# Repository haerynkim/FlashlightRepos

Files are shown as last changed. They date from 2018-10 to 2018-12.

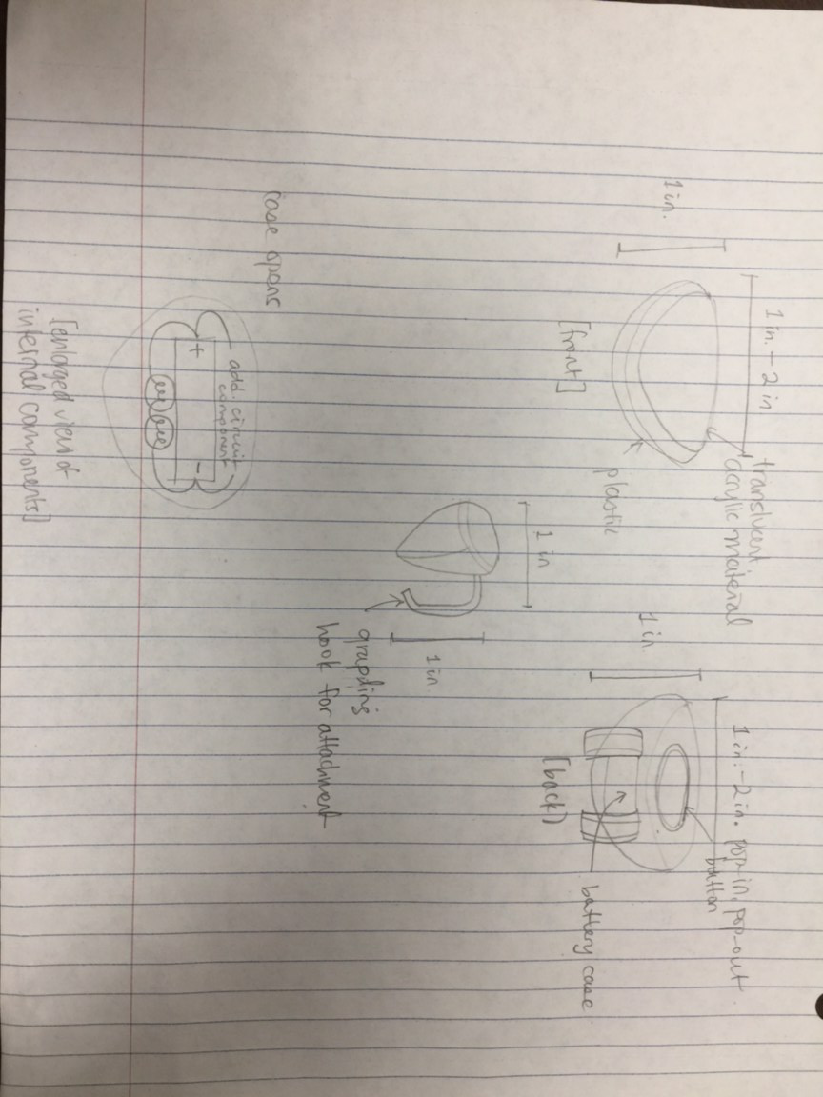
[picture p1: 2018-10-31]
design_sketch.jpeg

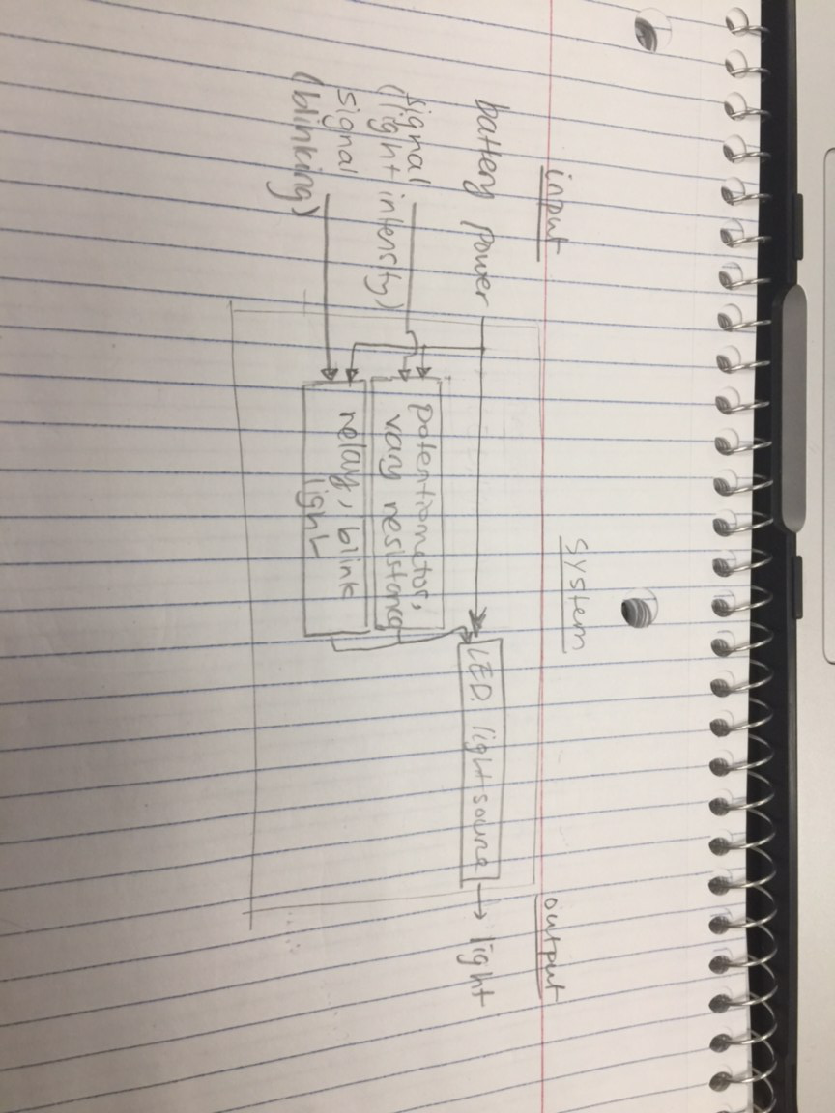
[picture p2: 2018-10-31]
block_diag.jpeg

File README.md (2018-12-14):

# FlashlightRepos
Final video submission URL: https://youtu.be/8UVXDF8A7WE<br/>
*note: I did not indicate on Sakai but I submitted course evaluations in class.

## How To
This design is protable lightbox and pulse sensor. To turn the device on, toggle the switch ON. An initiation screen will appear and in a few seconds, the red LED will turn on. To cycle through various modes, simply push down on the pushbutton. On every fourth push of the cycle, the LCD will display the pulse readings. You can attach or detach the pulse sensor at any moment by attaching or removing the earclip to your earlobes.<br/>
To replace the battery, simply open the box and unscrew the 1/8" bolts and expose the battery underneath. The battery cap is easily removable, and the battery replaceable.

## Features of the Device

### Software
* Debounce, interrupt on pushbutton
* Max BPM resets if max BPM remains over 215 bpm for greater than 20 seconds

### Hardware
* Green 3mm LED on PCB to indicate connection to power source and battery life (with diminishing brightness)
* 5.5 x 4.0 (cm) double-sided PCB with ground plane

### Mechanical
* Easy mount, easy install
* Tight latch and hinge design
* (-) LED without lightpipe

### Extra
* Pulse sensor: measures pulse at 9600 bauds rate. Can be attached to earlobe or finger.
* LED display: "Haeryn's Light Box: Thank You Matt Brown!" logo and continous display of current BPM and max BPM
* Indicates maximum BPM measured since device turned ON.

### Extra specifications

| Spec | Measured |
|---|---|
| Size(cm) | 6x7x5  |
| Weight(g) | 127.6g |
| Power draw(mA)  | 65-70  |
| Runtime ON(hr)  | 8.90 |
| Runtime OFF(hr) | inf |
| Cost($) | 35.15  |

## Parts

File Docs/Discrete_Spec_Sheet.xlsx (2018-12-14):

Parts | Voltage | Cost | Power draw
5mm Red LED | 3.3-5.5 | $0.35 | 20mA
3mm Green LED | 3.3-5.5 | $0.35 | 20mA
Atmega 328P |  | $5.99 | 1mA
Seeed OLED Display 0.96" |  | $14.90 | 20mA
Adafruit Pulsesensor |  | $1.38 | 4mA
16MHz crystal |  | $0.75
22pF capacitor
7805T 5V regulator |  | $0.99
150ohm resistor |  | $0.30
10kohm resistor |  | $0.30
220ohm resistor |  | $0.30
Panasonic 9V battery |  | $4.99
DPST switch |  | $3.80
pushbutton |  | $0.75
total |  | $35.15

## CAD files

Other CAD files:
Mechanical/Final_CAD.f3d
Mechanical/New_HingedBox_wLatch_v2.f3d
Mechanical/OldVersions/New_HingedBox_wLatch_v2.f3d
Mechanical/OldVersions/lightbox_v1.f3d
Mechanical/lightbox_v1.f3d

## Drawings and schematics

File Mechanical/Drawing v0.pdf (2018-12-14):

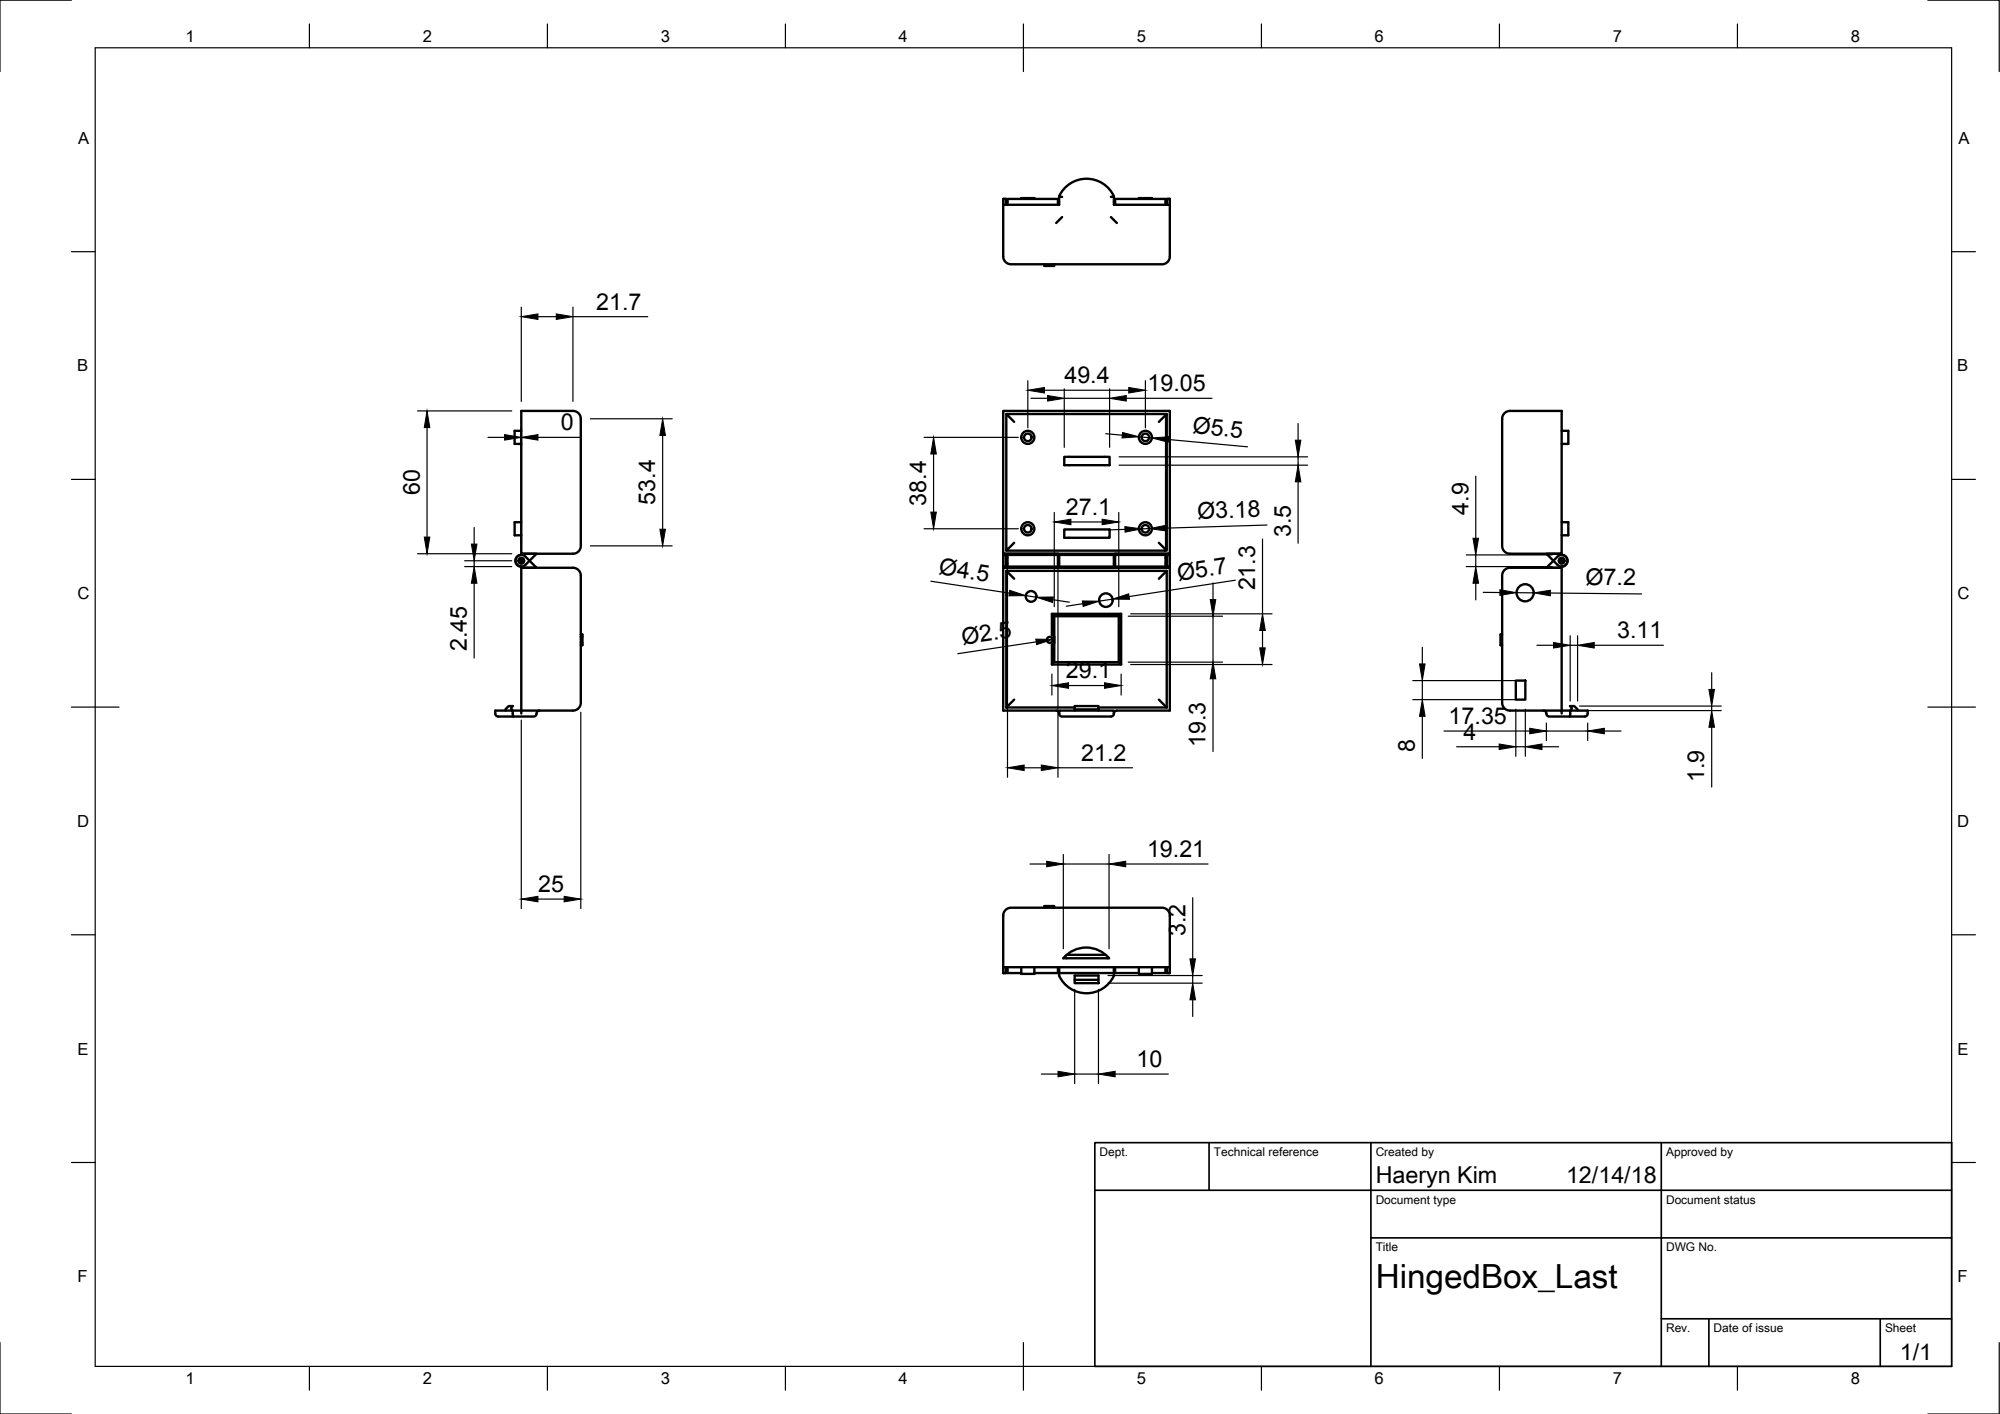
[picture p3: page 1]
Haeryn Kim 53.4 60

Dept. | Technical reference | Created by 12/14/18 | Approved by

Document type | Document status

Title HingedBox_Last | DWG No.

Rev. | Date of issue | Sheet 1/1

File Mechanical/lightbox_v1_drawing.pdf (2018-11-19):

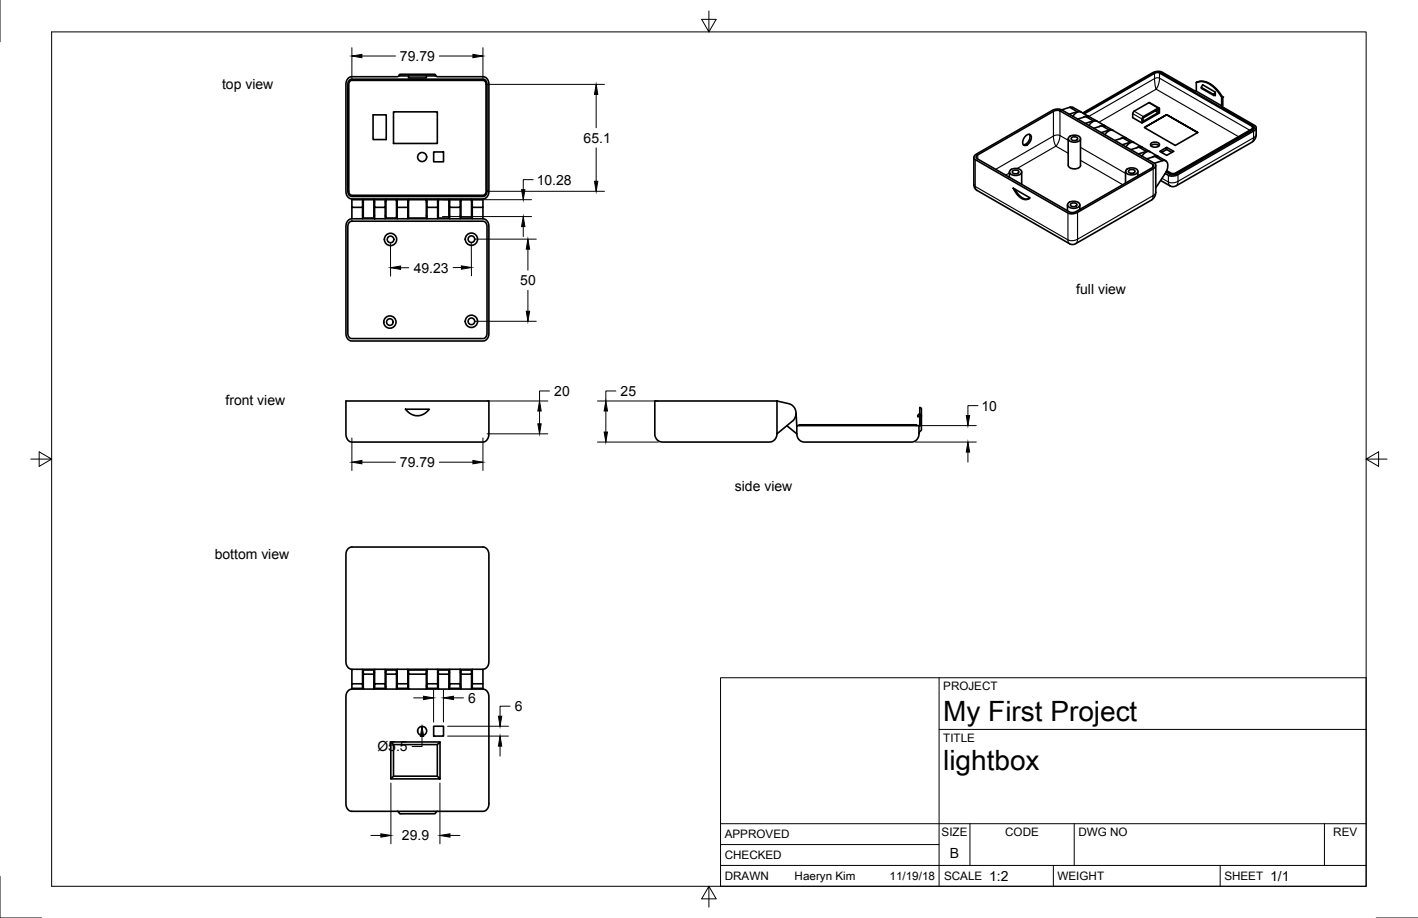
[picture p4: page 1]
SIZE; CODE; DWG NO; REV; Haeryn Kim; full view; top view; front view; bottom view; side view

PROJECT
My First Project
lightbox

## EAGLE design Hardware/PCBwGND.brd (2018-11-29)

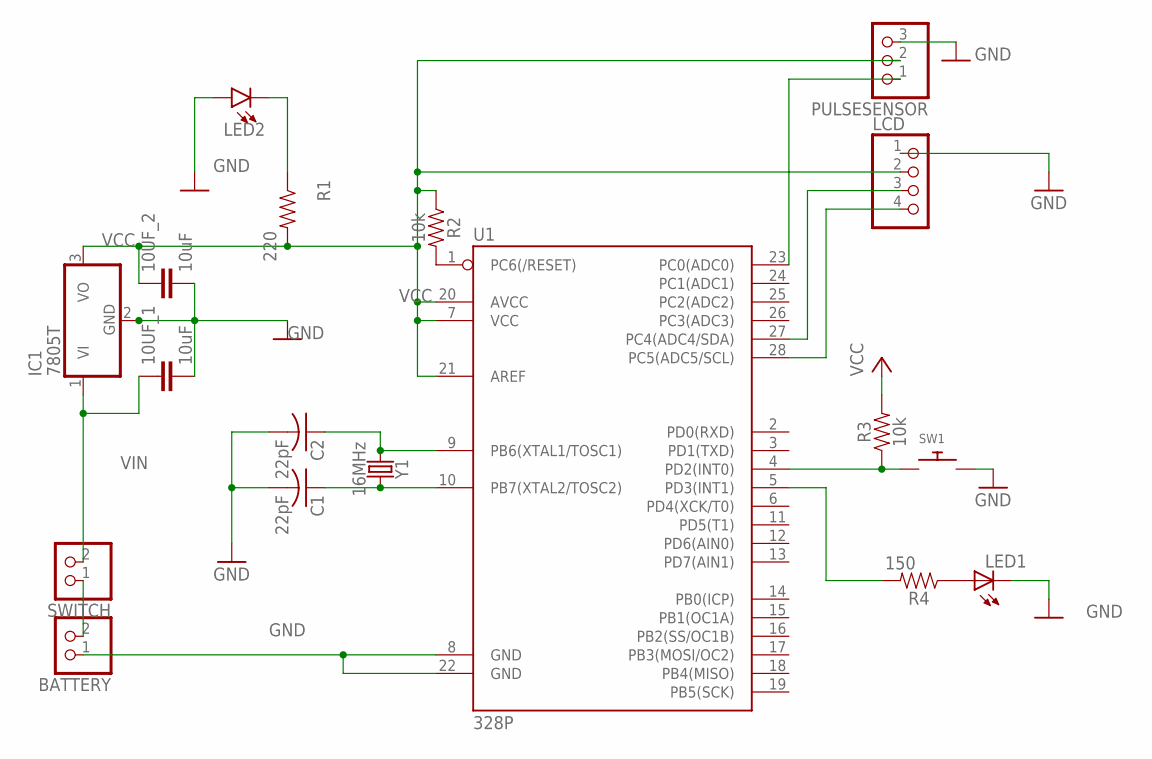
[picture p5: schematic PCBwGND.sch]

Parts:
10UF_1, 10UF_2: 10uF; CAP-PTH-2.54
BATTERY: PINHD-1X2; 1X02
C1, C2: 22pF; C025-024X044
IC1: 7805T; TO220H
LCD: PINHD-1X4; 1X04
LED1: LED5MM
LED2: LED3MM; LED_3MM
PULSESENSOR: PINHD-1X3; 1X03
R1: 220; AXIAL-0.3
R2, R3: 10k; AXIAL-0.3
R4: 150; AXIAL-0.3
SW1: SWITCH_PUSHBUTTONEVQ-PE; TACT_PANA-EVQ
SWITCH: PINHD-1X2; 1X02
U1: 328P; DIP28
Y1: 16MHz; HC49US

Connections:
GND: 10UF_1.2, 10UF_2.2, BATTERY.1, C1.2, C2.2, IC1.2 (GND), LCD.1, LED1.K (C), LED2.A, PULSESENSOR.3, SW1.P$2, U1.8 (GND), U1.22 (GND)
unnamed: BATTERY.2, SWITCH.1
unnamed: LED1.A, R4.P$1 (1)
unnamed: LED2.K (C), R1.P$1 (1)
PC0/ADC0: PULSESENSOR.1, U1.23 (PC0(ADC0))
PD2: R4.P$2 (2), U1.5 (PD3(INT1))
PD3: R3.P$1 (1), SW1.P$1, U1.4 (PD2(INT0))
RESET: R2.P$2 (2), U1.1 (PC6(/RESET))
SCL: LCD.4, U1.28 (PC5(ADC5/SCL))
SDA: LCD.3, U1.27 (PC4(ADC4/SDA))
VCC: 10UF_2.1, IC1.3 (VO), LCD.2, PULSESENSOR.2, R1.P$2 (2), R2.P$1 (1), R3.P$2 (2), U1.7 (VCC), U1.20 (AVCC), U1.21 (AREF)
VIN: 10UF_1.1, IC1.1 (VI), SWITCH.2
XTAL1: C2.1, U1.9 (PB6(XTAL1/TOSC1)), Y1.1
XTAL2: C1.1, U1.10 (PB7(XTAL2/TOSC2)), Y1.2

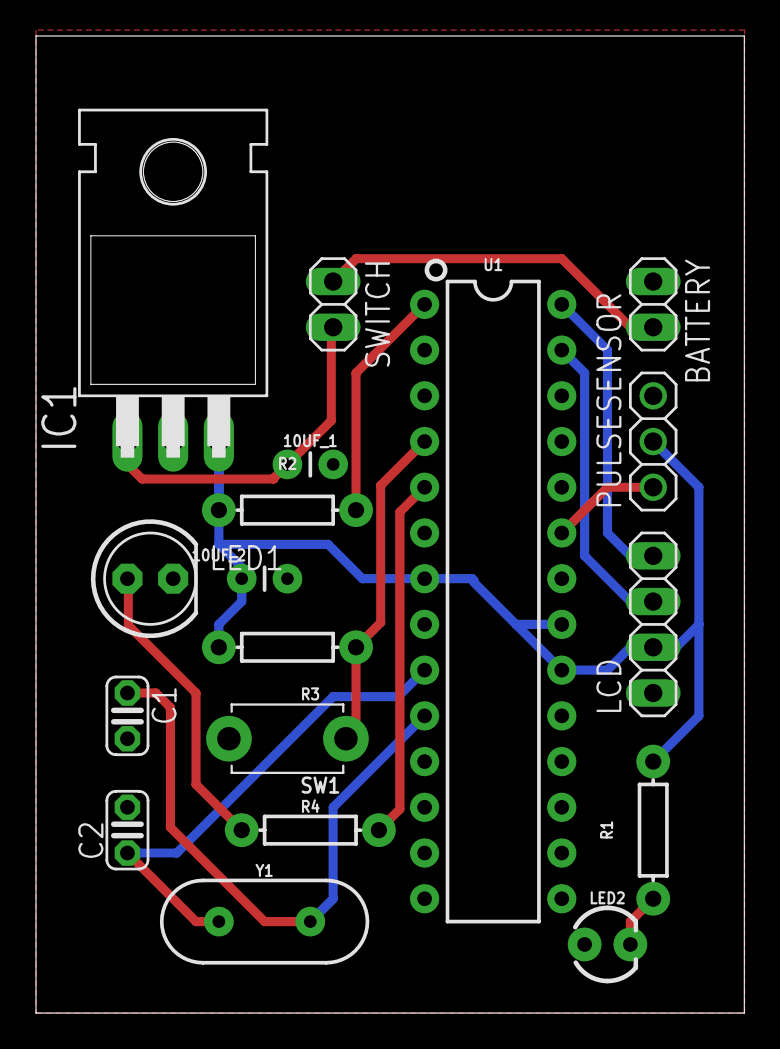
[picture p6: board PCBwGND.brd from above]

Board: 2 copper layers, 39.4 x 54.3 mm, 18 parts (0 on the bottom side), 14 nets.

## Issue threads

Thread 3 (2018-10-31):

Please review my hand-drawn PCB schematic and sketch of the case.

haerynkim, 2018-10-31:
They are files named Mechanical Design in the Mechanical folder and PCBschematic in the Electronics folder. They can be open by any PDF viewer. Would appreciate any comment e.g. this looks dumb, please make more complex, etc.

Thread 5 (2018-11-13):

Schematic / PCB Review

mlp6, 2018-11-13:
Looking good... not sure about functionality, but board layout is getting there.  What was the difference b/w v1 and v2?

sphaerobolus, 2018-11-13:
Schematic looks pretty good.

increase trace width. 20mil where you can, otherwise 12mil.

looks like a trace going to R3 doesn't quite make it all the way.

The crystal footprint isn't quite right. The crystal we use has pins 0.2" (200mil) apart.

150 Ohm pull up resistor is too small. 10k, maybe.

Closed 2024-08-24.

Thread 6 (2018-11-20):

Milestone05 Review

ps178, 2018-11-20:
Please create issues for milestone reviews.

Your CAD design looks great. My one note is about the hinges. I think its great you wanted to take more challenge and do hinges. I would be cautious about them though because I'm not sure how well the 3D printer can print it. I think you should try to print this design early on to make sure the hinges do work.

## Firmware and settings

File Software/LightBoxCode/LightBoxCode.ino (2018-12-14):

/*
  LightBoxCode
  

  modified 20 Nov 2018
  by Haeryn Kim
  
  http://github.com/haerynkim/FlashlightRepos
*/
#define USE_ARDUINO_INTERRUPTS true
#include <PulseSensorPlayground.h>
#include <Wire.h>
#include <SeeedOLED.h>

// Define constants:
const int interruptPin = 2;
int PWM_max = 255;
int ledPin = 3;
const int PULSE_INPUT = 0;
static const unsigned char myLogo[] PROGMEM ={
  0xff, 0xff, 0xff, 0xff, 0xff, 0xff, 0xff, 0xff, 0xff, 0xff, 0xff, 0xff, 0xff, 0xff, 0xff, 0xff, 
  0xff, 0xff, 0xff, 0xff, 0xff, 0xff, 0xff, 0xff, 0xff, 0xff, 0xff, 0xff, 0xff, 0xff, 0xff, 0xff, 
  0xff, 0xff, 0xff, 0xff, 0xff, 0xff, 0xff, 0xff, 0xff, 0xff, 0xff, 0xff, 0xff, 0xff, 0xff, 0xff, 
  0xff, 0xff, 0xff, 0xff, 0xff, 0xff, 0xff, 0xff, 0xff, 0xff, 0xff, 0xff, 0xff, 0xff, 0xff, 0xff, 
  0xff, 0xff, 0xff, 0xff, 0xff, 0xff, 0xff, 0xff, 0xff, 0xff, 0xff, 0xff, 0xff, 0xff, 0xff, 0xff, 
  0xff, 0xff, 0xff, 0xff, 0xff, 0xff, 0xff, 0xff, 0xff, 0xff, 0xff, 0xff, 0xff, 0xff, 0xff, 0xff, 
  0x7f, 0x2f, 0x27, 0xb7, 0xb7, 0x87, 0xcf, 0xff, 0x0f, 0x07, 0x07, 0xf7, 0x07, 0x07, 0x0f, 0xff, 
  0xef, 0x07, 0x07, 0xff, 0xff, 0x4f, 0x07, 0x07, 0xb7, 0x07, 0x07, 0x4f, 0xff, 0xff, 0xff, 0xff, 
  0xff, 0xff, 0xff, 0xff, 0xff, 0xff, 0xff, 0xff, 0xff, 0xff, 0xff, 0xff, 0xff, 0xff, 0xff, 0xff, 
  0xff, 0xff, 0xff, 0xff, 0xff, 0xff, 0xff, 0x07, 0xff, 0xff, 0xff, 0xff, 0xff, 0xff, 0xff, 0xff, 
  0xff, 0xff, 0xff, 0xff, 0xff, 0xff, 0xff, 0xff, 0xff, 0xff, 0xff, 0xff, 0xff, 0xff, 0xff, 0xff, 
  0xff, 0xff, 0xff, 0xff, 0xff, 0xff, 0xff, 0xff, 0xff, 0xff, 0xff, 0xff, 0xff, 0xff, 0xff, 0xff, 
  0xff, 0xff, 0xff, 0xff, 0xff, 0xff, 0xff, 0xff, 0xff, 0xff, 0xff, 0xff, 0xff, 0xff, 0xff, 0xff, 
  0xff, 0xff, 0xff, 0xff, 0xff, 0xff, 0xff, 0xff, 0xff, 0xff, 0xff, 0xff, 0xff, 0xff, 0xff, 0xff, 
  0xfe, 0xfe, 0xfe, 0xff, 0xff, 0xff, 0xff, 0xff, 0xfe, 0xfe, 0xfe, 0xff, 0xfe, 0xfe, 0xfe, 0xff, 
  0xff, 0xfe, 0xfe, 0xfe, 0xff, 0xfe, 0xfe, 0xfe, 0xff, 0xfe, 0xfe, 0xfe, 0xff, 0xff, 0xff, 0xff, 
  0xff, 0xff, 0xff, 0xff, 0xff, 0xff, 0xff, 0xff, 0xf3, 0xf3, 0xe7, 0xcf, 0xdf, 0xff, 0x7f, 0x7f, 
  0x3f, 0x9f, 0x9f, 0xcf, 0xcf, 0xcf, 0xef, 0xec, 0xef, 0xcf, 0xcf, 0xcf, 0x9f, 0x01, 0x01, 0x01, 
  0x01, 0x7f, 0xff, 0xff, 0xff, 0x01, 0x01, 0x01, 0x01, 0xff, 0x0f, 0x07, 0x07, 0x07, 0xf7, 0xf7, 
  0xf7, 0xf7, 0x07, 0x07, 0x07, 0x07, 0xff, 0x0f, 0x07, 0x07, 0x07, 0xf7, 0x37, 0x37, 0x37, 0x07, 
  0x07, 0x0f, 0xff, 0xff, 0x07, 0x07, 0x07, 0x07, 0xf7, 0xf7, 0xf7, 0x87, 0x07, 0x07, 0xcf, 0xff, 
  0xff, 0xc7, 0x07, 0x07, 0x3f, 0x3f, 0x3f, 0x3f, 0x07, 0x07, 0x07, 0x07, 0xff, 0x07, 0x07, 0x07, 
  0x07, 0xf7, 0xf7, 0xf7, 0xf7, 0x07, 0x07, 0x07, 0x0f, 0xff, 0xe1, 0xe1, 0xe1, 0xf1, 0xff, 0xcf, 
  0xcf, 0xc7, 0xc7, 0xd7, 0xd7, 0xd7, 0xd7, 0x17, 0x17, 0x17, 0x1f, 0xff, 0xff, 0xff, 0xff, 0xff, 
  0xff, 0xbf, 0x3f, 0x3f, 0x3f, 0x3f, 0x3f, 0xbf, 0xff, 0xff, 0xff, 0x0f, 0x83, 0xf8, 0xfc, 0xfe, 
  0xff, 0xff, 0xff, 0xff, 0xff, 0xff, 0xff, 0xff, 0xff, 0xff, 0xff, 0xff, 0xff, 0xfc, 0xfc, 0xfc, 
  0x0c, 0x00, 0x02, 0x0e, 0xfe, 0xfc, 0xfc, 0xfc, 0xfc, 0xff, 0xfe, 0xfc, 0xfc, 0x8c, 0x8d, 0x8d, 
  0xff, 0xff, 0x7c, 0x1c, 0x1c, 0x1c, 0x9f, 0x9e, 0x9c, 0x1c, 0x1c, 0x1d, 0x1d, 0xfd, 0xfd, 0x0d, 
  0x0d, 0x0f, 0x9f, 0x9f, 0x9c, 0x9c, 0x1c, 0x1c, 0x1f, 0x7f, 0xff, 0xff, 0x9f, 0x0f, 0x0f, 0x0f, 
  0x0f, 0x9f, 0x9d, 0x9d, 0x9d, 0x9d, 0x9d, 0xfd, 0x0c, 0x0c, 0x0c, 0x0e, 0x9f, 0x9c, 0x9c, 0x9c, 
  0x1c, 0x1f, 0x3f, 0x7f, 0xff, 0x7c, 0x3c, 0x1c, 0x1c, 0x9f, 0x9f, 0x9f, 0x9f, 0x1f, 0x1f, 0x3e, 
  0x7e, 0xfc, 0x1c, 0x1d, 0x1d, 0x1d, 0xfd, 0xfc, 0xfc, 0xfc, 0x1e, 0x1f, 0x1f, 0x3f, 0xff, 0xff, 
  0xff, 0xff, 0xff, 0xff, 0xff, 0xff, 0xff, 0xff, 0xff, 0xff, 0xff, 0xe0, 0x83, 0x3f, 0xff, 0xff, 
  0xff, 0xff, 0xff, 0xdf, 0x0f, 0x0f, 0x9f, 0x9f, 0x9f, 0x0f, 0x8f, 0xff, 0xff, 0xff, 0xff, 0xff, 
  0x60, 0x00, 0x80, 0xe0, 0xef, 0xef, 0xef, 0xe0, 0xe0, 0xe0, 0xe0, 0xff, 0xff, 0xe0, 0xe0, 0xe0, 
  0xff, 0xff, 0xfc, 0xec, 0xec, 0xec, 0xed, 0xed, 0xef, 0xe0, 0xe0, 0xe0, 0xf0, 0xff, 0xff, 0xe0, 
  0xe0, 0xe0, 0xff, 0xff, 0xff, 0xff, 0xe0, 0xe0, 0xe0, 0xe0, 0xff, 0xff, 0xff, 0xf0, 0xe0, 0xe0, 
  0xe0, 0xef, 0xef, 0xe1, 0xe1, 0xe1, 0xf1, 0xff, 0xe0, 0xe0, 0xe0, 0xe0, 0xef, 0xef, 0xef, 0xef, 
  0xe0, 0xf0, 0xf0, 0xf0, 0xff, 0xf0, 0xe0, 0xe0, 0xe0, 0xef, 0xef, 0xef, 0xef, 0xe0, 0xe0, 0xf0, 
  0xf0, 0xff, 0xe1, 0xe1, 0xe1, 0xe0, 0xfe, 0xfe, 0xfe, 0xfe, 0xe0, 0xe1, 0xe1, 0xe1, 0xff, 0xff, 
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
};

// Define variables subject to change:
volatile bool buttonState = HIGH;
bool lastButtonState = HIGH;
int buttonPushCounter = 0;
int maxBPM = 0;
int BPM = 0;
unsigned long lastTime = 0;
unsigned long debounceTime = 300;
unsigned long currentTime = 0;

PulseSensorPlayground pulseSensor;

// the setup function runs once when you press reset or power the board
void setup() {
  SeeedOled.init(); //initialize SeeedOLED display
  SeeedOled.clearDisplay(); //clear the screen and set start position to top left corner
  SeeedOled.drawBitmap((unsigned char*) myLogo,1024);   // 1024 = 128 Pixels * 64 Pixels / 8
  delay(1000);
  SeeedOled.clearDisplay();
  SeeedOled.setNormalDisplay(); //Set display to normal mode (i.e non-inverse mode)
  SeeedOled.setPageMode(); //Set addressing mode to Page Mode  
  Serial.begin(9600);
  pulseSensor.begin(); //initialize pulse sensor
  pulseSensor.analogInput(PULSE_INPUT); //initialize pin A0 as analog input pin for pulse sensor
  pulseSensor.setSerial(Serial);
  pinMode(interruptPin, INPUT); //initialize pin 2 as interrupt pin for pushbutton
  attachInterrupt(digitalPinToInterrupt(interruptPin), changestate, FALLING);
  pinMode(ledPin, OUTPUT); //initialize digital pin 3 as an output for LED.
  
}


// the loop function runs over and over again forever
void loop() {
  currentTime = millis();
  int nowButtonState = digitalRead(interruptPin);
  int BPM = pulseSensor.getBeatsPerMinute();
  if (BPM>maxBPM){
    maxBPM = BPM;
  }
  if ((maxBPM>215) && (millis()-currentTime>20000)) { // max BPM is reset if BPM>215 for over 20 sec.
    maxBPM = 0;
  }
  switch (buttonPushCounter) {
    case 0:
      analogWrite(ledPin, int(PWM_max/4));
      break;
    case 1:
      analogWrite(ledPin, int(PWM_max/2));
      break;
    case 2:
      digitalWrite(ledPin, PWM_max);
      break;
    case 3:
      digitalWrite(ledPin, PWM_max);
      delay(500);
      digitalWrite(ledPin, 0);
      delay(500);
      break;
    case 4:
      delay(20);
      SeeedOled.setTextXY(0,0);
      SeeedOled.putString("BPM:");
      SeeedOled.setTextXY(0,5);
      SeeedOled.putNumber(BPM);SeeedOled.putString("  ");
      SeeedOled.setTextXY(1,0);
      SeeedOled.putString("Max BPM:");SeeedOled.putString("  ");
      SeeedOled.setTextXY(1,9);
      SeeedOled.putNumber(maxBPM);
      //}
      break;
  }
  lastButtonState = nowButtonState;
}

// the if statement detects if the button has been pushed and changes the value of the state variable, buttonState
void changestate() {
  if ((millis() - lastTime) > debounceTime) {
    buttonState = !buttonState;
    buttonPushCounter ++;
    buttonPushCounter = buttonPushCounter % 5;
  }
}

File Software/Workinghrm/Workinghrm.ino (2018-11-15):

/*
  ButtonBlink

  This code is capable of turning on and off a function that dims an LED every second. 
  This function is turned on when the switch is on, and turned off when the switch is off.

  modified 19 May 2018
  by Haeryn Kim

  This code is part of a project available in the public domain.
  
  http://github.com/haerynkim/FlashlightRepos
*/
#define USE_ARDUINO_INTERRUPTS true
#include <PulseSensorPlayground.h>
#include <Wire.h>

// Define constants:
const int interruptPin = 2;
int PWM_max = 255;
int ledPin = 3;
const int PULSE_INPUT = 0;


// Define variables subject to change:
volatile bool buttonState = HIGH;
bool lastButtonState = HIGH;
int buttonPushCounter = 0;
int THRES = 520;

PulseSensorPlayground pulseSensor;

// the setup function runs once when you press reset or power the board
void setup() {
  /*
     Use 115200 baud because that's what the Processing Sketch expects to read,
     and because that speed provides about 11 bytes per millisecond.

     If we used a slower baud rate, we'd likely write bytes faster than
     they can be transmitted, which would mess up the timing
     of readSensor() calls, which would make the pulse measurement
     not work properly.
  */
  Serial.begin(9600);
  pulseSensor.begin();
  // initialize interruptPin (pin 2) as an input.
  pinMode(interruptPin, INPUT);
  attachInterrupt(digitalPinToInterrupt(interruptPin), changestate, FALLING);
  // initialize digital pin 3 as an output.
  pinMode(ledPin, OUTPUT);
  pulseSensor.analogInput(PULSE_INPUT);
  pulseSensor.setSerial(Serial);
  pulseSensor.setThreshold(THRES);

}

int i = 0;
int sum = 0;

// the loop function runs over and over again forever
void loop() {
  int BPM = pulseSensor.getBeatsPerMinute();
  for (i=0;i<20;i++){
    if (pulseSensor.sawStartOfBeat()) {
      int peak = pulseSensor.getLatestSample();
      Serial.println(peak);
      sum = sum + peak;
    }
    break;
  }
  
  switch (5) {
    case 0:
      digitalWrite(ledPin, 0);
      break;
    case 1:
      analogWrite(ledPin, int(PWM_max/4));
      break;
    case 2:
      analogWrite(ledPin, int(PWM_max/2));
      break;
    case 3:
      digitalWrite(ledPin, PWM_max);
      break;
    case 4:
      digitalWrite(ledPin, PWM_max);
      delay(500);
      digitalWrite(ledPin, 0);
      delay(500);
      break;
    case 5:
      delay(20);
      //if (pulseSensor.sawStartOfBeat()) {
        //Serial.print("BPM: ");
        //Serial.println(BPM);
      break;
  }
  lastButtonState = buttonState;
}

// the if statement detects if the button has been pushed and changes the value of the state variable, buttonState
void changestate() {
  buttonState = !buttonState;
  buttonPushCounter ++;
}

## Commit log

2018-10-19 Add Arduino code ButtonBlink.ino
    Makes the switch button work with one LED function.
2018-11-05 Adding backup iterations of working Arduino code
2018-11-06 Add file of working heart rate monitor version with fixed threshold
    [Workinghrm.ino]
2018-11-12 Add working version Eagle schematic and PCB for initial review
    [Lightbox.brd, Lightbox.sch]
2018-11-12 Added missing values and correct connections to Atmega328p
    [Lightbox2.brd, Lightbox2.sch]
2018-11-12 Working code that reads BPM from pulse sensor without hard-coded threshold
2018-11-12 Arduino libraries for SeeedOLED display and PulseSensor
2018-11-12 Solve issue with overwriting digits on LCD display and add logo for initial setup display
    [WorkingBPM.ino]
2018-11-15 Increase trace thickness and replace wrong components
    [Lightbox2.brd, Lightbox2.sch]
2018-11-19 Add dimensions and replace battery with 2pin header
    [Lightbox2.brd, Lightbox2.sch]
2018-11-19 milestone 05 2d drawing and 3d fusion360 model
    [lightbox_v1.f3d]
2018-11-20 Schematic and PCB design for final review
    [Lightbox2.brd, Lightbox2.sch]
2018-11-28 Arduino to Breadboard working video
2018-11-29 Add Final PCB design and remove first PCB iteration
    [Lightbox.brd, PCB.brd, PCB.sch]
2018-11-29 Add ground plane to reduce photoetching area
    [PCBwGND.brd, PCBwGND.sch]
2018-12-03 Add new hinged box design for modified PCB. Added parametric design.
    [New_HingedBox70mm_v1.f3d]
2018-12-04 Update CAD design with latch
    [New_HingedBox70mm_v1.f3d, New_HingedBox_wLatch_v2.f3d]
2018-12-04 Add video of PCB and all components working
2018-12-14 Push all necessary files, clean directories
    [Discrete_Technical_Spec_Sheet.xlsx, Final_CAD.f3d, New_HingedBox_wLatch_v2.f3d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]
2018-12-14 Re-do previous commit before too-large sized file
    [Discrete_Spec_Sheet.xlsx, Discrete_Technical_Spec_Sheet.xlsx]

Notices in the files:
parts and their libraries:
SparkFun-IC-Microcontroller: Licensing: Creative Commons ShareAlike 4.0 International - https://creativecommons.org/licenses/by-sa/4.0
